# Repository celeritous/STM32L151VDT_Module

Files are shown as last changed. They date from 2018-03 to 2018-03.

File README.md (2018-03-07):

# STM32L151VDT_Module
This repository is for an STM32L151/152 Cortex M3 32bit low power ARM  processor module. The design supports any of the STM32L151 or 152 processors in the QFP100 package. It is designed primarily for battery powered applications. 

The design is in KiCad and is released under the CERN OHL Ver 1.2 It is on a 50mm x 50mm 4 layer PCB with two 38 Pin dual row 100mil headers for user power and IO. There is no on-board voltage regulation so the user must supply regulated 1.8V-3.3V power to the board. Voltages in excess of this may damage the board. The board may operate as low as 1.65V but not all peripherals will operate at this voltage and full clock speed maynot be supported. The processor is capable of internal cclock speeds of up to 32MHz. 

Features include a USB FS port that can function as host or client as well as and optional uSD card slot and ESP-07 serial WiFi Module. The uSD card slot and WiFi module may be independently powered down by the processor to reduce power consumption. 

Along with the hardware design, the repository also contains a sample STM32CubeMX pin assignemt project file and a sample Atollic TrueStudio project file generated by the STM32CubeMX project file.

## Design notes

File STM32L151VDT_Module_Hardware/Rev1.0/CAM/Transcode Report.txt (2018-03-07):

   ---- Transcoding 'C:\Users\alitton\Dropbox\uBITX\STM32L151VDT_Module\CAM\STM32L151VDT_Module-B.Mask.gbs' ----   Sun Feb 04 23:11:05 2018

D11   --> D100
D12   --> D101
D13   --> D102
D14   --> D103
D15   --> D104
D16   --> D105
D17   --> D106
D18   --> D107
D19   --> D108
D20   --> D109
-----------------------------------------------------------------

   ---- Transcoding 'C:\Users\alitton\Dropbox\uBITX\STM32L151VDT_Module\CAM\STM32L151VDT_Module-B.SilkS.gbo' ----   Sun Feb 04 23:11:05 2018

D11   --> D110
D12   --> D111
D13   --> D112
D14   --> D113
D15   --> D114
-----------------------------------------------------------------

   ---- Transcoding 'C:\Users\alitton\Dropbox\uBITX\STM32L151VDT_Module\CAM\STM32L151VDT_Module-Edge.Cuts.gm1' ----   Sun Feb 04 23:11:05 2018

D11   --> D115
-----------------------------------------------------------------

   ---- Transcoding 'C:\Users\alitton\Dropbox\uBITX\STM32L151VDT_Module\CAM\STM32L151VDT_Module-F.Cu.gtl' ----   Sun Feb 04 23:11:05 2018

D11   --> D116
D12   --> D117
D13   --> D118
D14   --> D119
D15   --> D120
D16   --> D121
D17   --> D122
D18   --> D123
D19   --> D124
D20   --> D125
D21   --> D126
D22   --> D127
D23   --> D128
-----------------------------------------------------------------

   ---- Transcoding 'C:\Users\alitton\Dropbox\uBITX\STM32L151VDT_Module\CAM\STM32L151VDT_Module-F.Mask.gts' ----   Sun Feb 04 23:11:05 2018

D11   --> D129
D12   --> D130
D13   --> D131
D14   --> D132
D15   --> D133
D16   --> D134
D17   --> D135
D18   --> D136
D19   --> D137
D20   --> D138
D21   --> D139
D22   --> D140
D23   --> D141
D24   --> D142
D25   --> D143
-----------------------------------------------------------------

   ---- Transcoding 'C:\Users\alitton\Dropbox\uBITX\STM32L151VDT_Module\CAM\STM32L151VDT_Module-F.SilkS.gto' ----   Sun Feb 04 23:11:05 2018

D11   --> D144
D12   --> D145
D13   --> D146
D14   --> D147
D15   --> D148
-----------------------------------------------------------------

   ---- Transcoding 'C:\Users\alitton\Dropbox\uBITX\STM32L151VDT_Module\CAM\STM32L151VDT_Module-GND.g2' ----   Sun Feb 04 23:11:07 2018

D11   --> D149
D12   --> D150
D13   --> D151
D14   --> D152
D15   --> D153
D16   --> D154
-----------------------------------------------------------------

   ---- Transcoding 'C:\Users\alitton\Dropbox\uBITX\STM32L151VDT_Module\CAM\STM32L151VDT_Module-PWR.g3' ----   Sun Feb 04 23:11:08 2018

D11   --> D155
D12   --> D156
D13   --> D157
D14   --> D158
D15   --> D159
D16   --> D160
-----------------------------------------------------------------

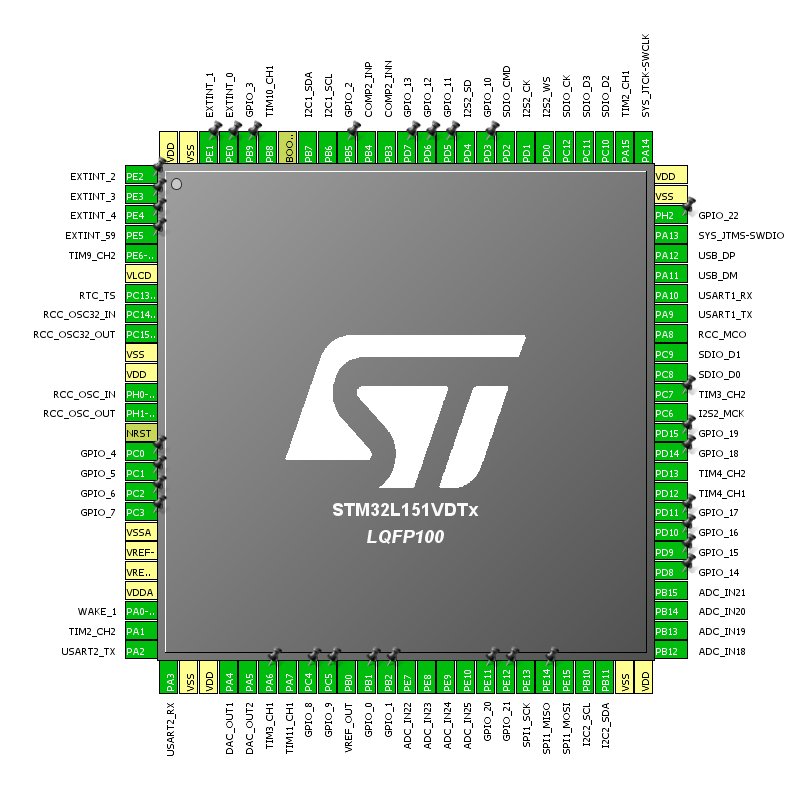
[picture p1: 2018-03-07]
STM32L151VDT_Module_Firmware/STM32L151VDT.PNG

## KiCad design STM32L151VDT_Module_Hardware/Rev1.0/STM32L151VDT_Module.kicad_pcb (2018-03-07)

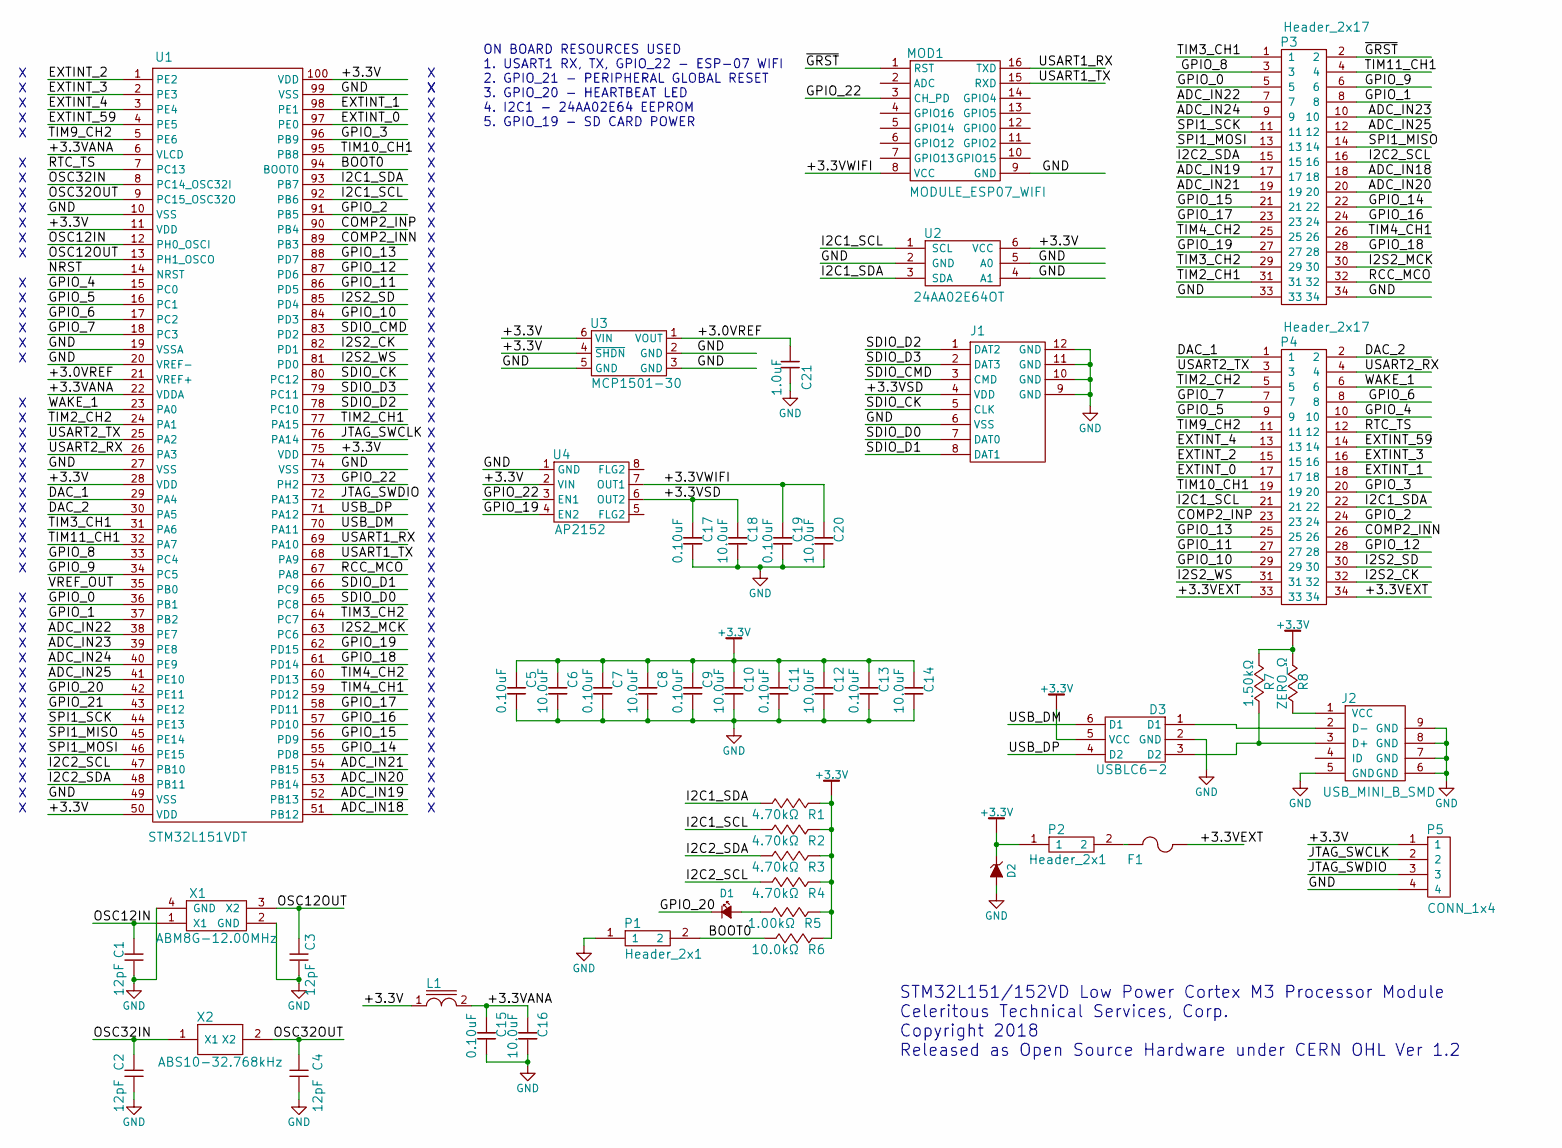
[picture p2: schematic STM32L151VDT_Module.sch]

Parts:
C1, C2, C3, C4: 12pF; P0603
C5, C7, C9, C11, C13, C15, C17, C19: 0.10uF; P0603
C6, C8, C10, C12, C14, C16, C18, C20: 10.0uF; P0603
C21: 1.0uF; P0603
D1: Led_Small; D0805
D2: SMLJ33ABCT; SOD128
D3: USBLC6-2; SOT23-6
F1: FUSE_PTC_.5A_33V; P1812
J1: SOCKET_MICRO_SD_SMT_3M; CONN_SDMICRO_3M
J2: USB_MINI_B_SMD; CONN_USB_UX60-MB
L1: FERRITE_BEAD; P0603
MOD1: MODULE_ESP07_WIFI
P1, P2: Header_2x1; Header_2x1_Shrouded_100mil
P3, P4: Header_2x17; Header_2x17_Shrouded_100mil
P5: CONN_1x4; Connector_1x4_100mil_TH
R1, R2, R3, R4: 4.70kΩ; P0603
R5: 1.00kΩ; P0603
R6: 10.0kΩ; P0603
R7: 1.50kΩ; P0603
R8: ZERO_Ω; P0603
U1: STM32L151VDT; QFP_100_14X14_0.5
U2: 24AA02E64OT; SOT23-6
U3: MCP1501-30; SOT23-6
U4: AP2152; SOIC_8
X1: ABM8G-12.00MHz; XTAL_3.2X2.5
X2: ABS10-32.768kHz; XTAL_1.8X4.9mm

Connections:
+3.3V: C5.1, C6.1, C7.1, C8.1, C9.1, C10.1, C11.1, C12.1, C13.1, C14.1, D2.K, D3.5 (VCC), L1.1, P2.1, P5.1, R1.2, R2.2, R3.2, R4.2, R5.2, R6.2, R7.1, R8.1, U1.11 (VDD), U1.28 (VDD), U1.50 (VDD), U1.75 (VDD), U1.100 (VDD), U2.6 (VCC), U3.4 (~SHDN), U3.6 (VIN), U4.2 (VIN)
/+3.0VREF: C21.1, U1.21 (VREF+), U3.1 (VOUT)
/+3.3VANA: C15.1, C16.1, L1.2, U1.6 (VLCD), U1.22 (VDDA)
/+3.3VEXT: F1.2, P4.33, P4.34
/+3.3VSD: C17.1, C18.1, J1.4 (VDD), U4.6 (OUT2)
/+3.3VWIFI: C19.1, C20.1, MOD1.8 (VCC), U4.7 (OUT1)
/ADC_IN18: P3.18, U1.51 (PB12)
/ADC_IN19: P3.17, U1.52 (PB13)
/ADC_IN20: P3.20, U1.53 (PB14)
/ADC_IN21: P3.19, U1.54 (PB15)
/ADC_IN22: P3.7, U1.38 (PE7)
/ADC_IN23: P3.10, U1.39 (PE8)
/ADC_IN24: P3.9, U1.40 (PE9)
/ADC_IN25: P3.12, U1.41 (PE10)
/BOOT0: P1.2, R6.1, U1.94 (BOOT0)
/COMP2_INN: P4.26, U1.89 (PB3)
/COMP2_INP: P4.23, U1.90 (PB4)
/DAC_1: P4.1, U1.29 (PA4)
/DAC_2: P4.2, U1.30 (PA5)
/EXTINT_0: P4.17, U1.97 (PE0)
/EXTINT_1: P4.18, U1.98 (PE1)
/EXTINT_2: P4.15, U1.1 (PE2)
/EXTINT_3: P4.16, U1.2 (PE3)
/EXTINT_4: P4.13, U1.3 (PE4)
/EXTINT_59: P4.14, U1.4 (PE5)
/GPIO_0: P3.5, U1.36 (PB1)
/GPIO_1: P3.8, U1.37 (PB2)
/GPIO_2: P4.24, U1.91 (PB5)
/GPIO_3: P4.20, U1.96 (PB9)
/GPIO_4: P4.10, U1.15 (PC0)
/GPIO_5: P4.9, U1.16 (PC1)
/GPIO_6: P4.8, U1.17 (PC2)
/GPIO_7: P4.7, U1.18 (PC3)
/GPIO_8: P3.3, U1.33 (PC4)
/GPIO_9: P3.6, U1.34 (PC5)
/GPIO_10: P4.29, U1.84 (PD3)
/GPIO_11: P4.27, U1.86 (PD5)
/GPIO_12: P4.28, U1.87 (PD6)
/GPIO_13: P4.25, U1.88 (PD7)
/GPIO_14: P3.22, U1.55 (PD8)
/GPIO_15: P3.21, U1.56 (PD9)
/GPIO_16: P3.24, U1.57 (PD10)
/GPIO_17: P3.23, U1.58 (PD11)
/GPIO_18: P3.28, U1.61 (PD14)
/GPIO_19: P3.27, U1.62 (PD15), U4.4 (EN2)
/GPIO_20: D1.K, U1.42 (PE11)
/GPIO_22: MOD1.3 (CH_PD), U1.73 (PH2), U4.3 (EN1)
/I2C1_SCL: P4.21, R2.1, U1.92 (PB6), U2.1 (SCL)
/I2C1_SDA: P4.22, R1.1, U1.93 (PB7), U2.3 (SDA)
/I2C2_SCL: P3.16, R4.1, U1.47 (PB10)
/I2C2_SDA: P3.15, R3.1, U1.48 (PB11)
/I2S2_CK: P4.32, U1.82 (PD1)
/I2S2_MCK: P3.30, U1.63 (PC6)
/I2S2_SD: P4.30, U1.85 (PD4)
/I2S2_WS: P4.31, U1.81 (PD0)
/JTAG_SWCLK: P5.2, U1.76 (PA14)
/JTAG_SWDIO: P5.3, U1.72 (PA13)
/OSC12IN: C1.1, U1.12 (PH0_OSCI), X1.1 (X1)
/OSC12OUT: C3.1, U1.13 (PH1_OSCO), X1.3 (X2)
/OSC32IN: C2.1, U1.8 (PC14_OSC32I), X2.1 (X1)
/OSC32OUT: C4.1, U1.9 (PC15_OSC32O), X2.2 (X2)
/RCC_MCO: P3.32, U1.67 (PA8)
/RTC_TS: P4.12, U1.7 (PC13)
/SDIO_CK: J1.5 (CLK), U1.80 (PC12)
/SDIO_CMD: J1.3 (CMD), U1.83 (PD2)
/SDIO_D0: J1.7 (DAT0), U1.65 (PC8)
/SDIO_D1: J1.8 (DAT1), U1.66 (PC9)
/SDIO_D2: J1.1 (DAT2), U1.78 (PC10)
/SDIO_D3: J1.2 (DAT3), U1.79 (PC11)
/SPI1_MISO: P3.14, U1.45 (PE14)
/SPI1_MOSI: P3.13, U1.46 (PE15)
/SPI1_SCK: P3.11, U1.44 (PE13)
/TIM2_CH1: P3.31, U1.77 (PA15)
/TIM2_CH2: P4.5, U1.24 (PA1)
/TIM3_CH1: P3.1, U1.31 (PA6)
/TIM3_CH2: P3.29, U1.64 (PC7)
/TIM4_CH1: P3.26, U1.59 (PD12)
/TIM4_CH2: P3.25, U1.60 (PD13)
/TIM9_CH2: P4.11, U1.5 (PE6)
/TIM10_CH1: P4.19, U1.95 (PB8)
/TIM11_CH1: P3.4, U1.32 (PA7)
/USART1_RX: MOD1.16 (TXD), U1.69 (PA10)
/USART1_TX: MOD1.15 (RXD), U1.68 (PA9)
/USART2_RX: P4.4, U1.26 (PA3)
/USART2_TX: P4.3, U1.25 (PA2)
/USB_DM: D3.6 (D1), U1.70 (PA11)
/USB_DP: D3.4 (D2), U1.71 (PA12)
/WAKE_1: P4.6, U1.23 (PA0)
/~GRST: MOD1.1 (RST), P3.2
GND: C1.2, C2.2, C3.2, C4.2, C5.2, C6.2, C7.2, C8.2, C9.2, C10.2, C11.2, C12.2, C13.2, C14.2, C15.2, C16.2, C17.2, C18.2, C19.2, C20.2, C21.2, D2.A, D3.2 (GND), J1.6 (VSS), J1.9 (GND), J1.10 (GND), J1.11 (GND), J1.12 (GND), J2.5 (GND), J2.6 (GND), J2.7 (GND), J2.8 (GND), J2.9 (GND), MOD1.9 (GND), P1.1, P3.33, P3.34, P5.4, U1.10 (VSS), U1.19 (VSSA), U1.20 (VREF-), U1.27 (VSS), U1.49 (VSS), U1.74 (VSS), U1.99 (VSS), U2.2 (GND), U2.4 (A1), U2.5 (A0), U3.2 (GND), U3.3 (GND), U3.5 (GND), U4.1 (GND), X1.2 (GND), X1.4 (GND)
unnamed: D1.A, R5.1
unnamed: D3.1 (D1), J2.2 (D-)
unnamed: D3.3 (D2), J2.3 (D+), R7.2
unnamed: F1.1, P2.2
unnamed: J2.1 (VCC), R8.2

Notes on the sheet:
ON BOARD RESOURCES USED 1. USART1 RX, TX, GPIO_22 - ESP-07 WIFI 2. GPIO_21 - PERIPHERAL GLOBAL RESET 3. GPIO_20 - HEARTBEAT LED 4. I2C1 - 24AA02E64 EEPROM 5. GPIO_19 - SD CARD POWER
STM32L151/152VD Low Power Cortex M3 Processor Module Celeritous Technical Services, Corp. Copyright 2018 Released as Open Source Hardware under CERN OHL Ver 1.2

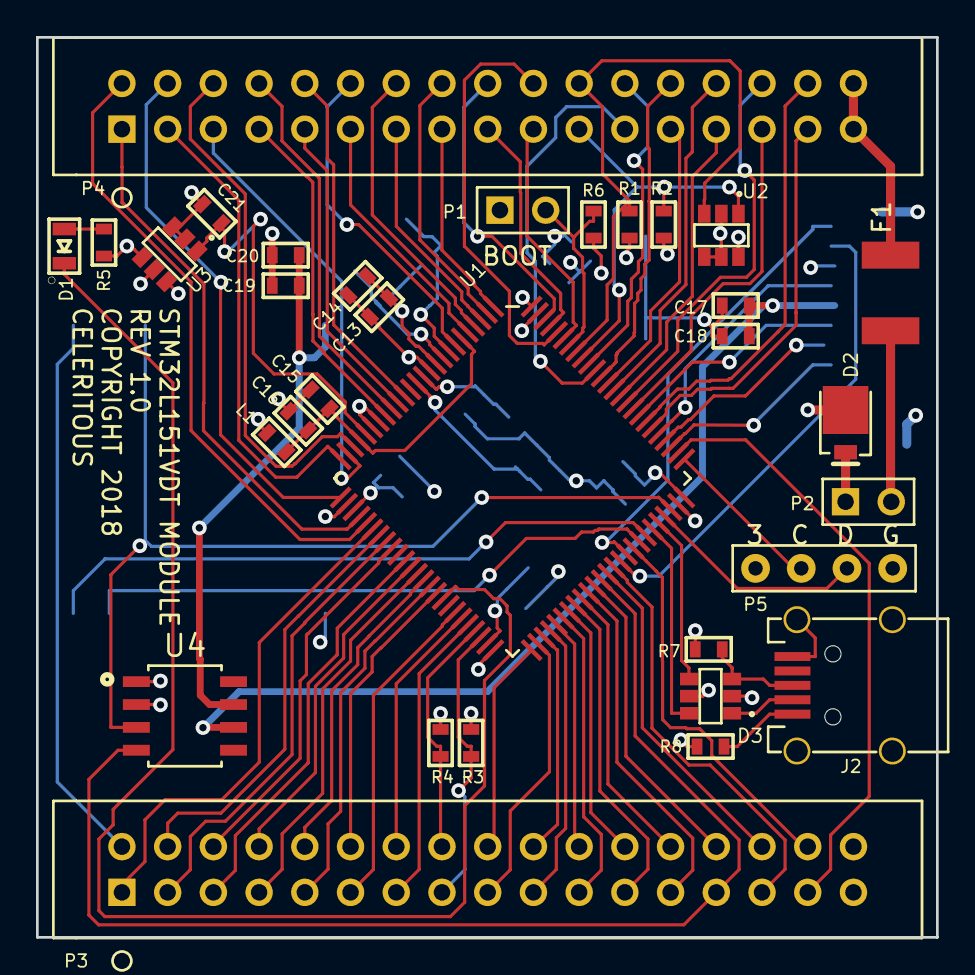
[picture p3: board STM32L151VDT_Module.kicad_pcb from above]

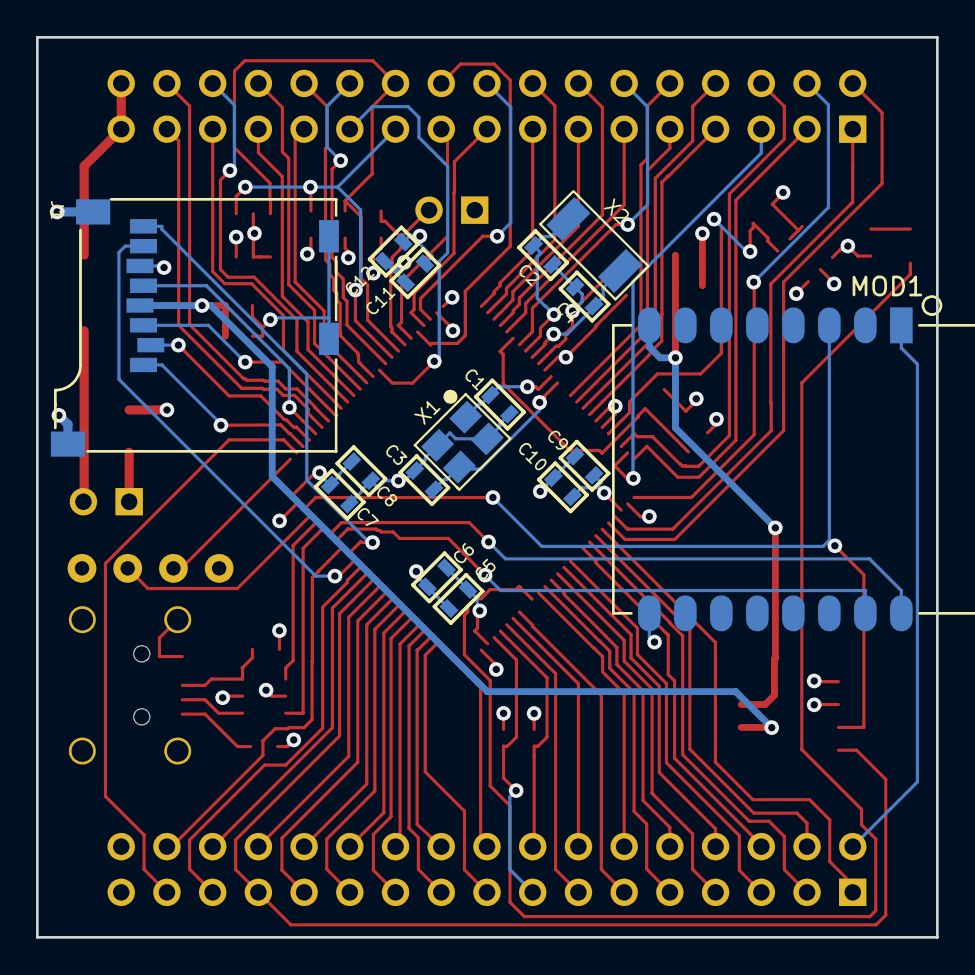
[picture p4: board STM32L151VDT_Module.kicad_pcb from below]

Board: 4 copper layers, 50.0 x 50.0 mm, 48 parts (16 on the bottom side), 95 nets.

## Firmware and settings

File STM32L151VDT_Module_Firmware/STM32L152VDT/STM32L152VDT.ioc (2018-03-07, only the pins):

Mcu.UserName=STM32L152VDTx
PA0-WKUP1.Signal=SYS_WKUP1
PA1.Signal=S_TIM2_CH2
PA10.Signal=USART1_RX
PA11.Signal=USB_DM
PA12.Signal=USB_DP
PA13.Signal=SYS_JTMS-SWDIO
PA14.Signal=SYS_JTCK-SWCLK
PA15.Signal=S_TIM2_CH1_ETR
PA2.Signal=USART2_TX
PA3.Signal=USART2_RX
PA4.Signal=COMP_DAC1_group
PA5.Signal=COMP_DAC2_group
PA6.Signal=S_TIM3_CH1
PA7.Signal=S_TIM11_CH1
PA8.Signal=RCC_MCO
PA9.Signal=USART1_TX
PB0.Signal=SYS_V_REF_OUT
PB1.Signal=GPIO_Input
PB10.Signal=I2C2_SCL
PB11.Signal=I2C2_SDA
PB12.Signal=ADC_IN18
PB13.Signal=ADC_IN19
PB14.Signal=ADC_IN20
PB15.Signal=ADC_IN21
PB2.Signal=GPIO_Input
PB3.Signal=COMP2_INM
PB4.Signal=COMP2_INP
PB5.Signal=GPIO_Input
PB6.Signal=I2C1_SCL
PB7.Signal=I2C1_SDA
PB8.Signal=S_TIM10_CH1
PB9.Signal=GPIO_Input
PC0.Signal=GPIO_Input
PC1.Signal=GPIO_Input
PC10.Signal=SDIO_D2
PC11.Signal=SDIO_D3
PC12.Signal=SDIO_CK
PC13-WKUP2.Signal=RTC_TS
PC14-OSC32_IN.Signal=RCC_OSC32_IN
PC15-OSC32_OUT.Signal=RCC_OSC32_OUT
PC2.Signal=GPIO_Input
PC3.Signal=GPIO_Input
PC4.Signal=GPIO_Input
PC5.Signal=GPIO_Input
PC6.Signal=I2S2_MCK
PC7.Signal=S_TIM3_CH2
PC8.Signal=SDIO_D0
PC9.Signal=SDIO_D1
PD0.Signal=I2S2_WS
PD1.Signal=I2S2_CK
PD10.Signal=GPIO_Input
PD11.Signal=GPIO_Input
PD12.Signal=S_TIM4_CH1
PD13.Signal=S_TIM4_CH2
PD14.Signal=GPIO_Input
PD15.Signal=GPIO_Input
PD2.Signal=SDIO_CMD
PD3.Signal=GPIO_Input
PD4.Signal=I2S2_SD
PD5.Signal=GPIO_Input
PD6.Signal=GPIO_Input
PD7.Signal=GPIO_Input
PD8.Signal=GPIO_Input
PD9.Signal=GPIO_Input
PE0.Signal=GPXTI0
PE1.Signal=GPXTI1
PE10.Signal=ADC_IN25
PE11.Signal=GPIO_Input
PE12.Signal=GPIO_Input
PE13.Signal=SPI1_SCK
PE14.Signal=SPI1_MISO
PE15.Signal=SPI1_MOSI
PE2.Signal=GPXTI2
PE3.Signal=GPXTI3
PE4.Signal=GPXTI4
PE5.Signal=GPXTI5
PE6-WKUP3.Signal=S_TIM9_CH2
PE7.Signal=ADC_IN22
PE8.Signal=ADC_IN23
PE9.Signal=ADC_IN24
PH0-OSC_IN.Signal=RCC_OSC_IN
PH1-OSC_OUT.Signal=RCC_OSC_OUT
PH2.Signal=GPIO_Input

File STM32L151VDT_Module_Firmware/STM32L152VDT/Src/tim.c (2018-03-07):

/**
  ******************************************************************************
  * File Name          : TIM.c
  * Description        : This file provides code for the configuration
  *                      of the TIM instances.
  ******************************************************************************
  * This notice applies to any and all portions of this file
  * that are not between comment pairs USER CODE BEGIN and
  * USER CODE END. Other portions of this file, whether 
  * inserted by the user or by software development tools
  * are owned by their respective copyright owners.
  *
  * Copyright (c) 2018 STMicroelectronics International N.V. 
  * All rights reserved.
  *
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
  ******************************************************************************
  */

/* Includes ------------------------------------------------------------------*/
#include "tim.h"

#include "gpio.h"

TIM_HandleTypeDef htim2;
TIM_HandleTypeDef htim3;
TIM_HandleTypeDef htim4;
TIM_HandleTypeDef htim9;
TIM_HandleTypeDef htim10;
TIM_HandleTypeDef htim11;

/* TIM2 init function */
void MX_TIM2_Init(void)
{
  TIM_Encoder_InitTypeDef sConfig;
  TIM_MasterConfigTypeDef sMasterConfig;

  htim2.Instance = TIM2;
  htim2.Init.Prescaler = 0;
  htim2.Init.CounterMode = TIM_COUNTERMODE_UP;
  htim2.Init.Period = 0;
  htim2.Init.ClockDivision = TIM_CLOCKDIVISION_DIV1;
  sConfig.EncoderMode = TIM_ENCODERMODE_TI1;
  sConfig.IC1Polarity = TIM_ICPOLARITY_RISING;
  sConfig.IC1Selection = TIM_ICSELECTION_DIRECTTI;
  sConfig.IC1Prescaler = TIM_ICPSC_DIV1;
  sConfig.IC1Filter = 0;
  sConfig.IC2Polarity = TIM_ICPOLARITY_RISING;
  sConfig.IC2Selection = TIM_ICSELECTION_DIRECTTI;
  sConfig.IC2Prescaler = TIM_ICPSC_DIV1;
  sConfig.IC2Filter = 0;
  if (HAL_TIM_Encoder_Init(&htim2, &sConfig) != HAL_OK)
  {
    _Error_Handler(__FILE__, __LINE__);
  }

  sMasterConfig.MasterOutputTrigger = TIM_TRGO_RESET;
  sMasterConfig.MasterSlaveMode = TIM_MASTERSLAVEMODE_DISABLE;
  if (HAL_TIMEx_MasterConfigSynchronization(&htim2, &sMasterConfig) != HAL_OK)
  {
    _Error_Handler(__FILE__, __LINE__);
  }

}
/* TIM3 init function */
void MX_TIM3_Init(void)
{
  TIM_Encoder_InitTypeDef sConfig;
  TIM_MasterConfigTypeDef sMasterConfig;

  htim3.Instance = TIM3;
  htim3.Init.Prescaler = 0;
  htim3.Init.CounterMode = TIM_COUNTERMODE_UP;
  htim3.Init.Period = 0;
  htim3.Init.ClockDivision = TIM_CLOCKDIVISION_DIV1;
  sConfig.EncoderMode = TIM_ENCODERMODE_TI1;
  sConfig.IC1Polarity = TIM_ICPOLARITY_RISING;
  sConfig.IC1Selection = TIM_ICSELECTION_DIRECTTI;
  sConfig.IC1Prescaler = TIM_ICPSC_DIV1;
  sConfig.IC1Filter = 0;
  sConfig.IC2Polarity = TIM_ICPOLARITY_RISING;
  sConfig.IC2Selection = TIM_ICSELECTION_DIRECTTI;
  sConfig.IC2Prescaler = TIM_ICPSC_DIV1;
  sConfig.IC2Filter = 0;
  if (HAL_TIM_Encoder_Init(&htim3, &sConfig) != HAL_OK)
  {
    _Error_Handler(__FILE__, __LINE__);
  }

  sMasterConfig.MasterOutputTrigger = TIM_TRGO_RESET;
  sMasterConfig.MasterSlaveMode = TIM_MASTERSLAVEMODE_DISABLE;
  if (HAL_TIMEx_MasterConfigSynchronization(&htim3, &sMasterConfig) != HAL_OK)
  {
    _Error_Handler(__FILE__, __LINE__);
  }

}
/* TIM4 init function */
void MX_TIM4_Init(void)
{
  TIM_Encoder_InitTypeDef sConfig;
  TIM_MasterConfigTypeDef sMasterConfig;

  htim4.Instance = TIM4;
  htim4.Init.Prescaler = 0;
  htim4.Init.CounterMode = TIM_COUNTERMODE_UP;
  htim4.Init.Period = 0;
  htim4.Init.ClockDivision = TIM_CLOCKDIVISION_DIV1;
  sConfig.EncoderMode = TIM_ENCODERMODE_TI1;
  sConfig.IC1Polarity = TIM_ICPOLARITY_RISING;
  sConfig.IC1Selection = TIM_ICSELECTION_DIRECTTI;
  sConfig.IC1Prescaler = TIM_ICPSC_DIV1;
  sConfig.IC1Filter = 0;
  sConfig.IC2Polarity = TIM_ICPOLARITY_RISING;
  sConfig.IC2Selection = TIM_ICSELECTION_DIRECTTI;
  sConfig.IC2Prescaler = TIM_ICPSC_DIV1;
  sConfig.IC2Filter = 0;
  if (HAL_TIM_Encoder_Init(&htim4, &sConfig) != HAL_OK)
  {
    _Error_Handler(__FILE__, __LINE__);
  }

  sMasterConfig.MasterOutputTrigger = TIM_TRGO_RESET;
  sMasterConfig.MasterSlaveMode = TIM_MASTERSLAVEMODE_DISABLE;
  if (HAL_TIMEx_MasterConfigSynchronization(&htim4, &sMasterConfig) != HAL_OK)
  {
    _Error_Handler(__FILE__, __LINE__);
  }

}
/* TIM9 init function */
void MX_TIM9_Init(void)
{
  TIM_ClockConfigTypeDef sClockSourceConfig;
  TIM_MasterConfigTypeDef sMasterConfig;
  TIM_OC_InitTypeDef sConfigOC;

  htim9.Instance = TIM9;
  htim9.Init.Prescaler = 0;
  htim9.Init.CounterMode = TIM_COUNTERMODE_UP;
  htim9.Init.Period = 0;
  htim9.Init.ClockDivision = TIM_CLOCKDIVISION_DIV1;
  if (HAL_TIM_Base_Init(&htim9) != HAL_OK)
  {
    _Error_Handler(__FILE__, __LINE__);
  }

  sClockSourceConfig.ClockSource = TIM_CLOCKSOURCE_INTERNAL;
  if (HAL_TIM_ConfigClockSource(&htim9, &sClockSourceConfig) != HAL_OK)
  {
    _Error_Handler(__FILE__, __LINE__);
  }

  if (HAL_TIM_PWM_Init(&htim9) != HAL_OK)
  {
    _Error_Handler(__FILE__, __LINE__);
  }

  sMasterConfig.MasterOutputTrigger = TIM_TRGO_RESET;
  sMasterConfig.MasterSlaveMode = TIM_MASTERSLAVEMODE_DISABLE;
  if (HAL_TIMEx_MasterConfigSynchronization(&htim9, &sMasterConfig) != HAL_OK)
  {
    _Error_Handler(__FILE__, __LINE__);
  }

  sConfigOC.OCMode = TIM_OCMODE_PWM1;
  sConfigOC.Pulse = 0;
  sConfigOC.OCPolarity = TIM_OCPOLARITY_HIGH;
  sConfigOC.OCFastMode = TIM_OCFAST_DISABLE;
  if (HAL_TIM_PWM_ConfigChannel(&htim9, &sConfigOC, TIM_CHANNEL_2) != HAL_OK)
  {
    _Error_Handler(__FILE__, __LINE__);
  }

  HAL_TIM_MspPostInit(&htim9);

}
/* TIM10 init function */
void MX_TIM10_Init(void)
{
  TIM_ClockConfigTypeDef sClockSourceConfig;
  TIM_IC_InitTypeDef sConfigIC;

  htim10.Instance = TIM10;
  htim10.Init.Prescaler = 0;
  htim10.Init.CounterMode = TIM_COUNTERMODE_UP;
  htim10.Init.Period = 0;
  htim10.Init.ClockDivision = TIM_CLOCKDIVISION_DIV1;
  if (HAL_TIM_Base_Init(&htim10) != HAL_OK)
  {
    _Error_Handler(__FILE__, __LINE__);
  }

  sClockSourceConfig.ClockSource = TIM_CLOCKSOURCE_INTERNAL;
  if (HAL_TIM_ConfigClockSource(&htim10, &sClockSourceConfig) != HAL_OK)
  {
    _Error_Handler(__FILE__, __LINE__);
  }

  if (HAL_TIM_IC_Init(&htim10) != HAL_OK)
  {
    _Error_Handler(__FILE__, __LINE__);
  }

  sConfigIC.ICPolarity = TIM_INPUTCHANNELPOLARITY_RISING;
  sConfigIC.ICSelection = TIM_ICSELECTION_DIRECTTI;
  sConfigIC.ICPrescaler = TIM_ICPSC_DIV1;
  sConfigIC.ICFilter = 0;
  if (HAL_TIM_IC_ConfigChannel(&htim10, &sConfigIC, TIM_CHANNEL_1) != HAL_OK)
  {
    _Error_Handler(__FILE__, __LINE__);
  }

}
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

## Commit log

2018-03-07 Create README.md
    This is an STM32L151/152 low power processor module for QFP100 packaged devices. It is a 50mm x 50mm 4 Layer PCB with two 38 pin 100mil dual row headers. It features an optional uSD card slot and ESP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
    The design is done in KiCad and is released under the CERN Open Hardware License Version 1.2
2018-03-07 STM32L151/152 Processor Module
    This is an STM32L151/152 low power 32bit ARM Cortex M3 processor module. It is designed for use with the QFP100 packaged devices and brings out most IO for external use. A companion STM32CubeMX proje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
    The processor module is on a 50mm x 50mm 4 layer PCB with two 38 pin dual row 100mil headers provided for power and I/O. There is no on-board power regulation so the board must be fed with regulated 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
    Features include a USB FS Port and opt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
2018-03-07 Added Sample TrueStudio / CubeMX
    [STM32L151VDT_Module-B.Cu.gbl, STM32L151VDT_Module-B.Mask.gbs, STM32L151VDT_Module-B.SilkS.gbo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]

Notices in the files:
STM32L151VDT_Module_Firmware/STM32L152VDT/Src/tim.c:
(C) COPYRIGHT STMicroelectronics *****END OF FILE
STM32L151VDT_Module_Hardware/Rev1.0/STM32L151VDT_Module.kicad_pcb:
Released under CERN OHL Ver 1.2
